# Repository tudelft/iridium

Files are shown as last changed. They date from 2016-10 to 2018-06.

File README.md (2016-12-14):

IRIDIUM IR9523 CARRIER BOARD
============================



Open-source carrier board for iridium IR9523 OEM modem.

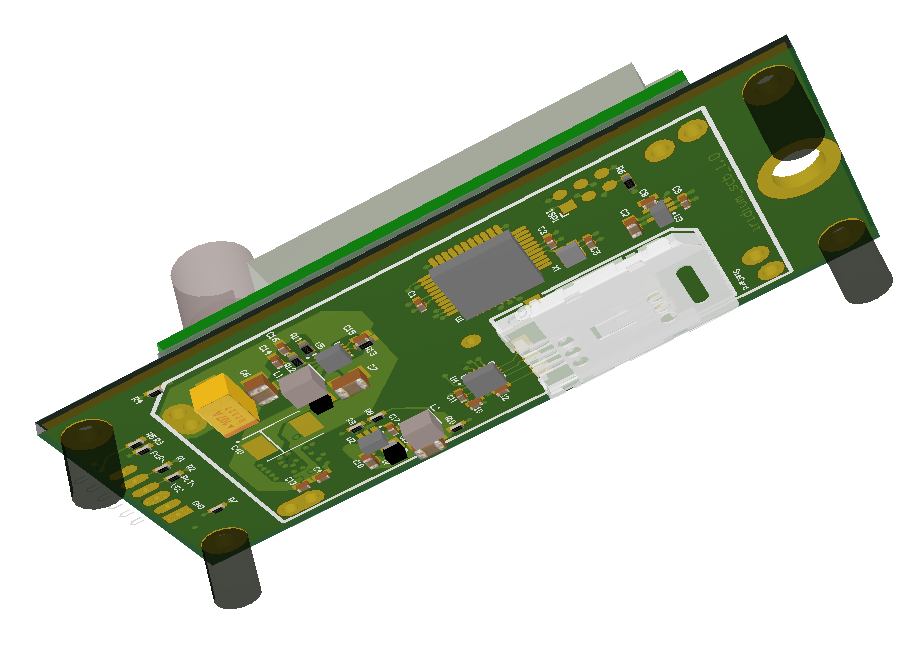
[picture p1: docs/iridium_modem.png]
Render of Iridium Carrier Board


Disclaimer:
-----------

 - An IRIDIUM IR9523 OEM module and an active subscription and simcard are required for this project.
 - The modems behave as transparent link. This means calls are answered automatically and all data sent to the module are tranmitted via space as soon as a connection is made.
 - Iridium antennas send strong signals and people must stay at a safe distance from the antenna. Consult all iridium documentation before use.

Licence:
--------

 - Software is released under **GPL3**
 - Hardware is released under **CC-BY-SA**

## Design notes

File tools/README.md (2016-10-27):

# Iridium Link
The Iridium Link tool configures the ground modem and initiates a call to the air modem. The ground modem firmware acts as an forwarder to the IR9523 OEM modem. This way the ground can be configured to call every number and forward all data over UDP.

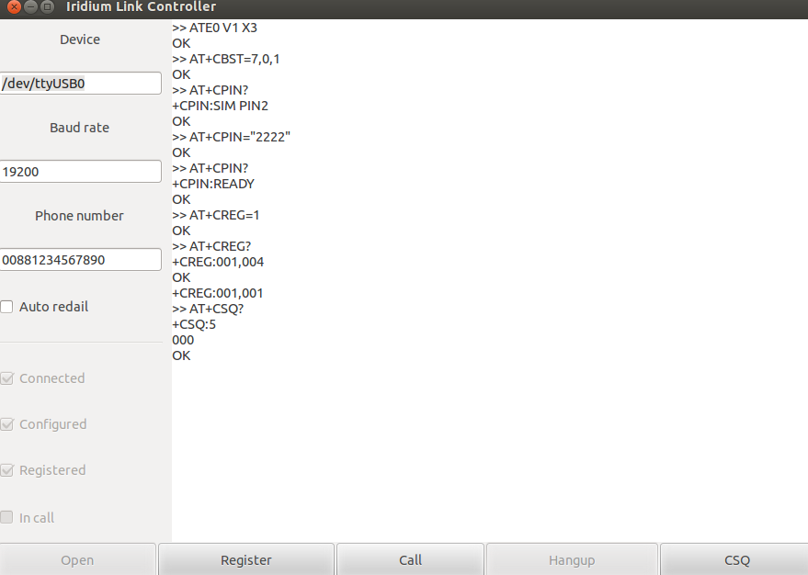
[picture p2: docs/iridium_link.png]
Iridium Link Program


## How to make a call
- Connect your ground modem with a serial cable to your computer (make sure it has the correct firmware)
- Start the `iridium_link.py` and enter the correct Serial port
- Press 'Open', this will setup the modem with the correct settings
- Press 'Register' to register the iridium device in the network
- Enter the correct phone number in the dialog
- Press 'Call' to initiate a call (this can take some time)

## Prerequisites
- pygtk 2.24.2
- pyserial 3.1.1
- Twisted 16.4.1

## FAQ

### I get a 'NO CARRIER' back
Please make sure you see the 'Registered' box checked, if not make sure you pressed 'Register'. Make sure the phone number is also correct. If both are correct try to press 'CSQ' which will return a signal quality, if this is '0' make sure you have placed your antenna aming at a clear sky.

### Where do I get the data
This tool will output data by default on UDP port '4242' and data can be send to UDP port '4243' on the local host. This will work by default with the Paparazzi Autopilot UDP link.

### I changed the SIM pin number
Make sure you also update the PIN number into the tool (this will be changeable in later versions). If not it won't be able to register.

### I cannot register to the network
If the 'Registered' box is never checked make sure your SIM card is correctly placed in the ground modem. Also make sure that your SIM card is activated by your provider.

### The ground modem doesn't respond
Make sure the ground modem is connected and turned on. Also make sure that the ground modem has the correct firmware (The ground and air modem have different versions).

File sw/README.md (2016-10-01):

# Firmware
 - the air modem is best programmed with iridium_air.hex which has firmware to automatically answer calls.
 - when also using iridium as ground modem, the board is best flashed with transparent firmware iridium_ground.hex. Use the python tool from the [tools](../tools) folder to dial.

## How to build
To build the software you have to run `make` in the `sw` folder. This will produce both the `iridium_air.elf` and the `iridium_ground.elf`.

## How to flash
To flash you either need to enter `make ground_program` or `make air_program` respectively for the ground and the air module. Note that this is using `avrdude` with an `avrispmkII` programmer.
If needed you can set the programmer using the `AVR_PROG=avrispmkII` make define.

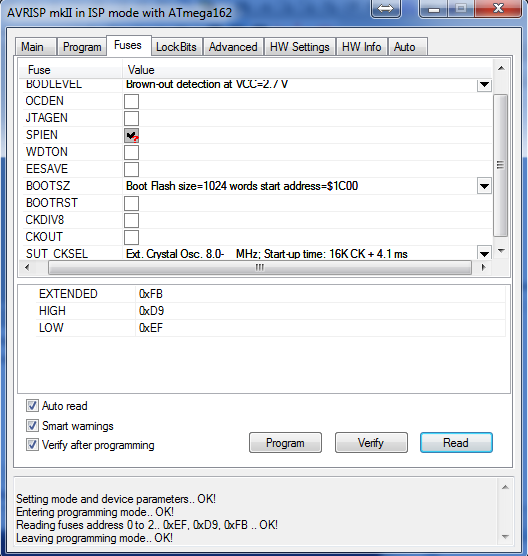
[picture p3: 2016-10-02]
sw/fuses.png

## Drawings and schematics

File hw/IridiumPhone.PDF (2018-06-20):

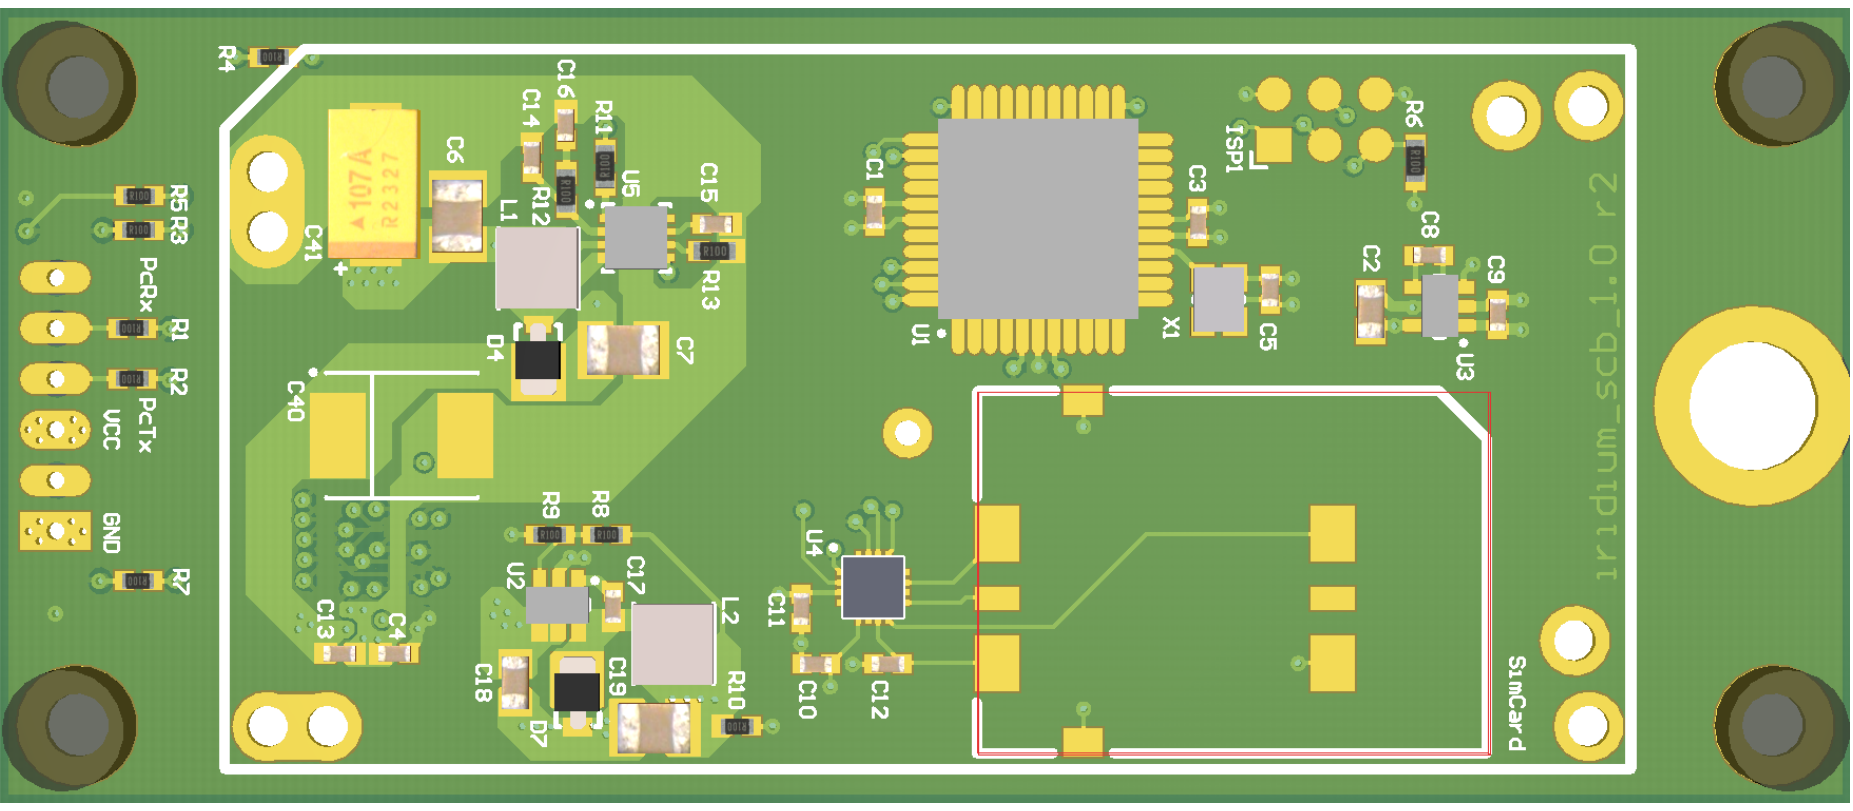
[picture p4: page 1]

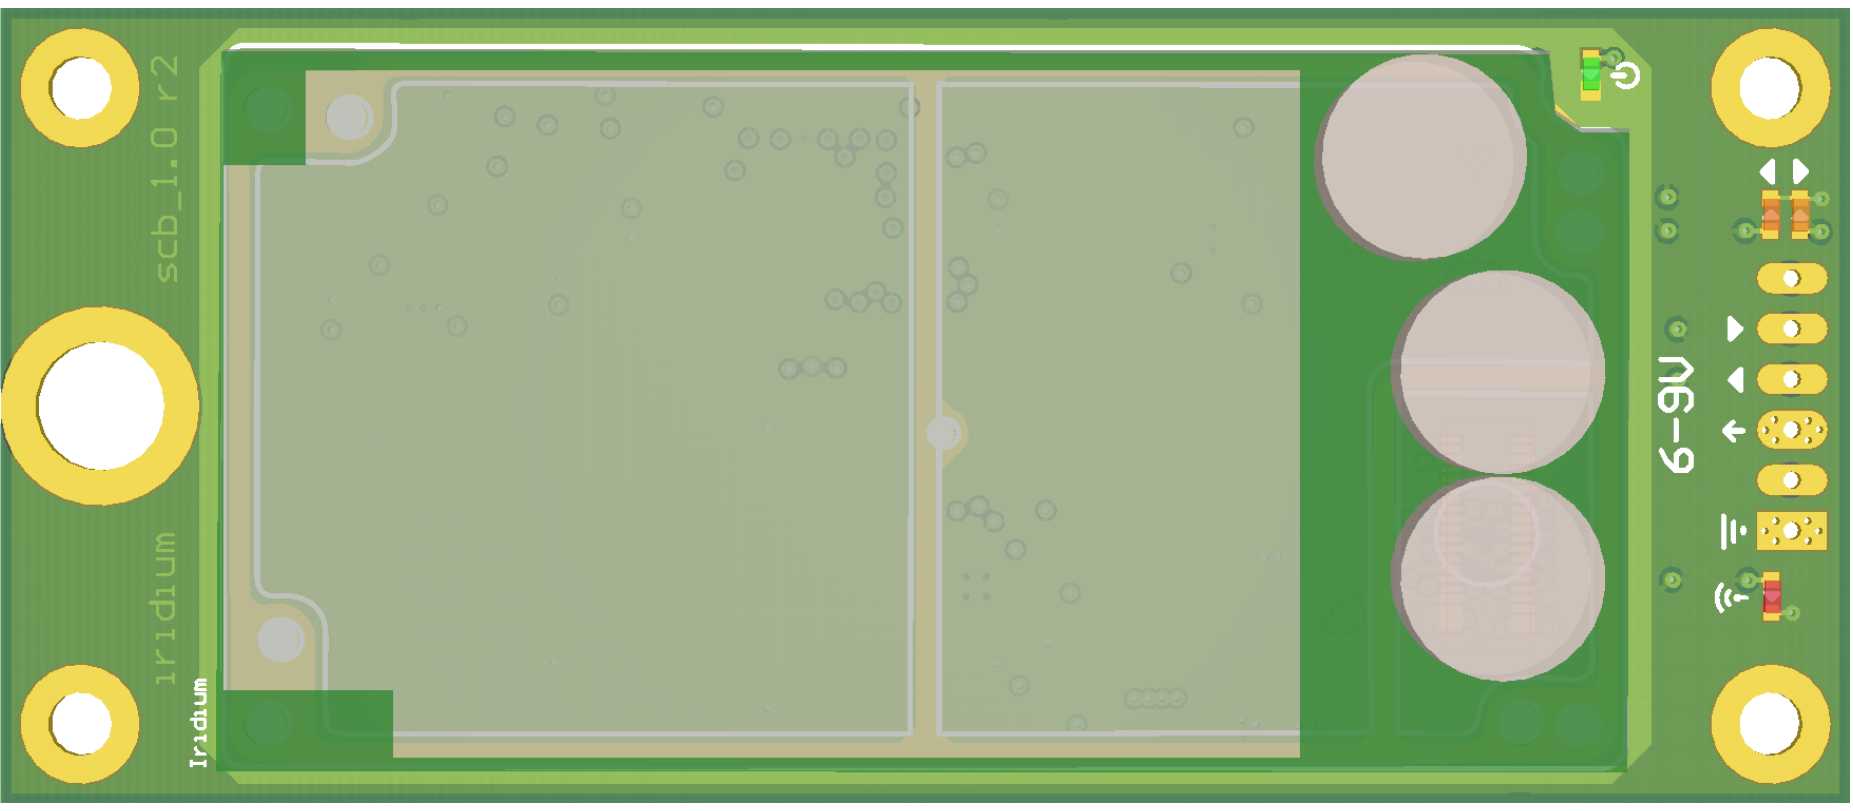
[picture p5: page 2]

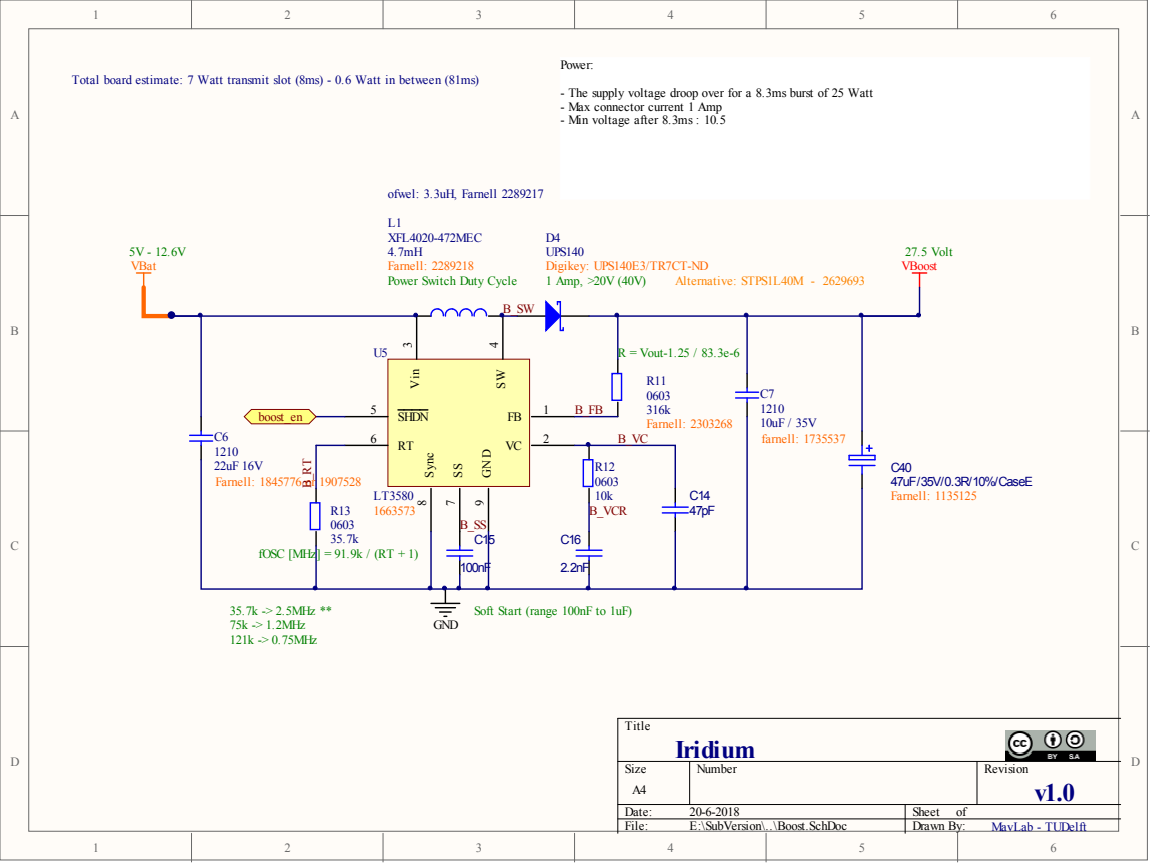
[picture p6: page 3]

Total board estimate: 7 Watt transmit slot (8ms) - 0.6 Watt in between (81ms)

- The supply voltage droop over for a 8.3ms burst of 25 Watt
- Max connector current 1 Amp
- Min voltage after 8.3ms : 10.5

Soft Start (range 100nF to 1uF)

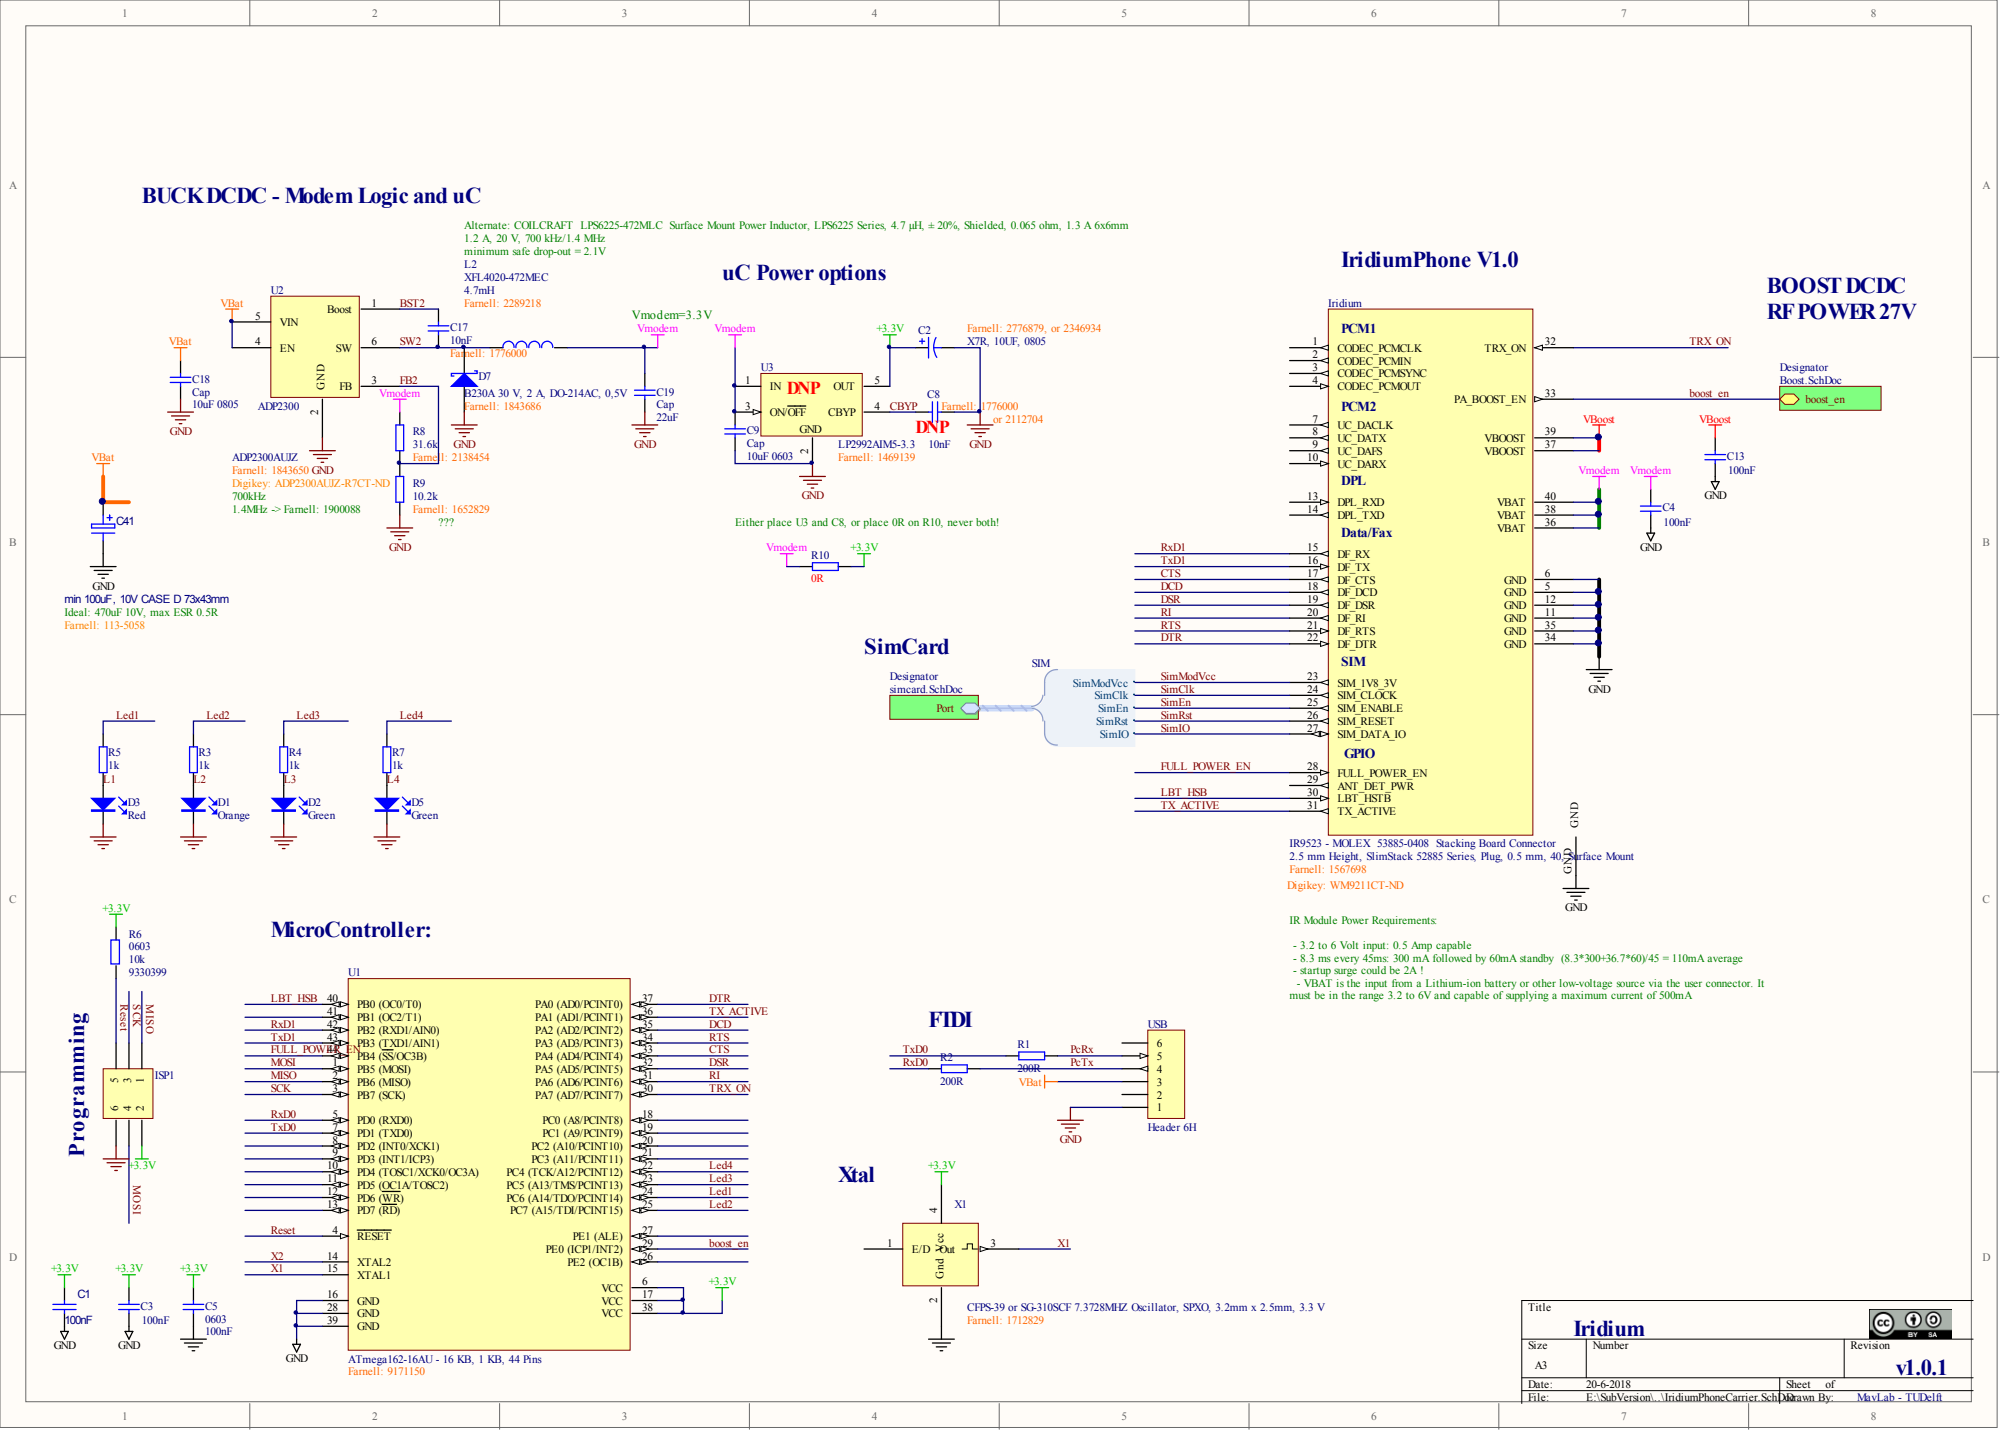
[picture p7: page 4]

BUCKDCDC - Modem Logic and uC

Alternate: COILCRAFT LPS6225-472MLC Surface Mount Power Inductor, LPS6225 Series, 4.7 µH, ± 20%, Shielded, 0.065 ohm, 1.3 A 6x6mm
1.2 A, 20 V, 700 kHz/1.4 MHz
minimum safe drop-out = 2.1V
XFL4020-472MEC
Farnell: 2289218

Either place U3 and C8, or place 0R on R10, never both!

IR9523 - MOLEX 53885-0408 Stacking Board Connector
2.5 mm Height, SlimStack 52885 Series, Plug, 0.5 mm, 40, Surface Mount
Farnell: 1567698
Digikey: WM9211CT-ND

IR Module Power Requirements:

- 3.2 to 6 Volt input: 0.5 Amp capable
- 8.3 ms every 45ms: 300 mA followed by 60mA standby (8.3*300+36.7*60)/45 = 110mA average
- startup surge could be 2A !
- VBAT is the input from a Lithium-ion battery or other low-voltage source via the user connector. It
must be in the range 3.2 to 6V and capable of supplying a maximum current of 500mA

CFPS-39 or SG-310SCF 7.3728MHZ Oscillator, SPXO, 3.2mm x 2.5mm, 3.3 V
Farnell: 1712829

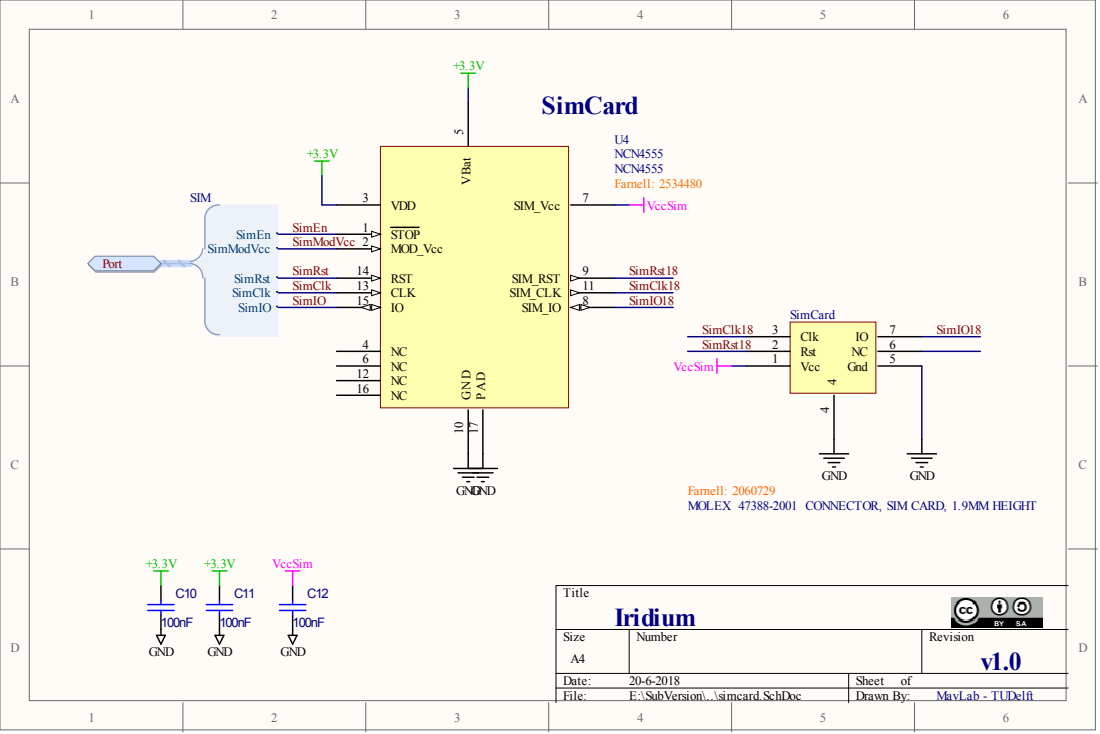
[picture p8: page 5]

Farnell: 2060729
MOLEX 47388-2001 CONNECTOR, SIM CARD, 1.9MM HEIGHT

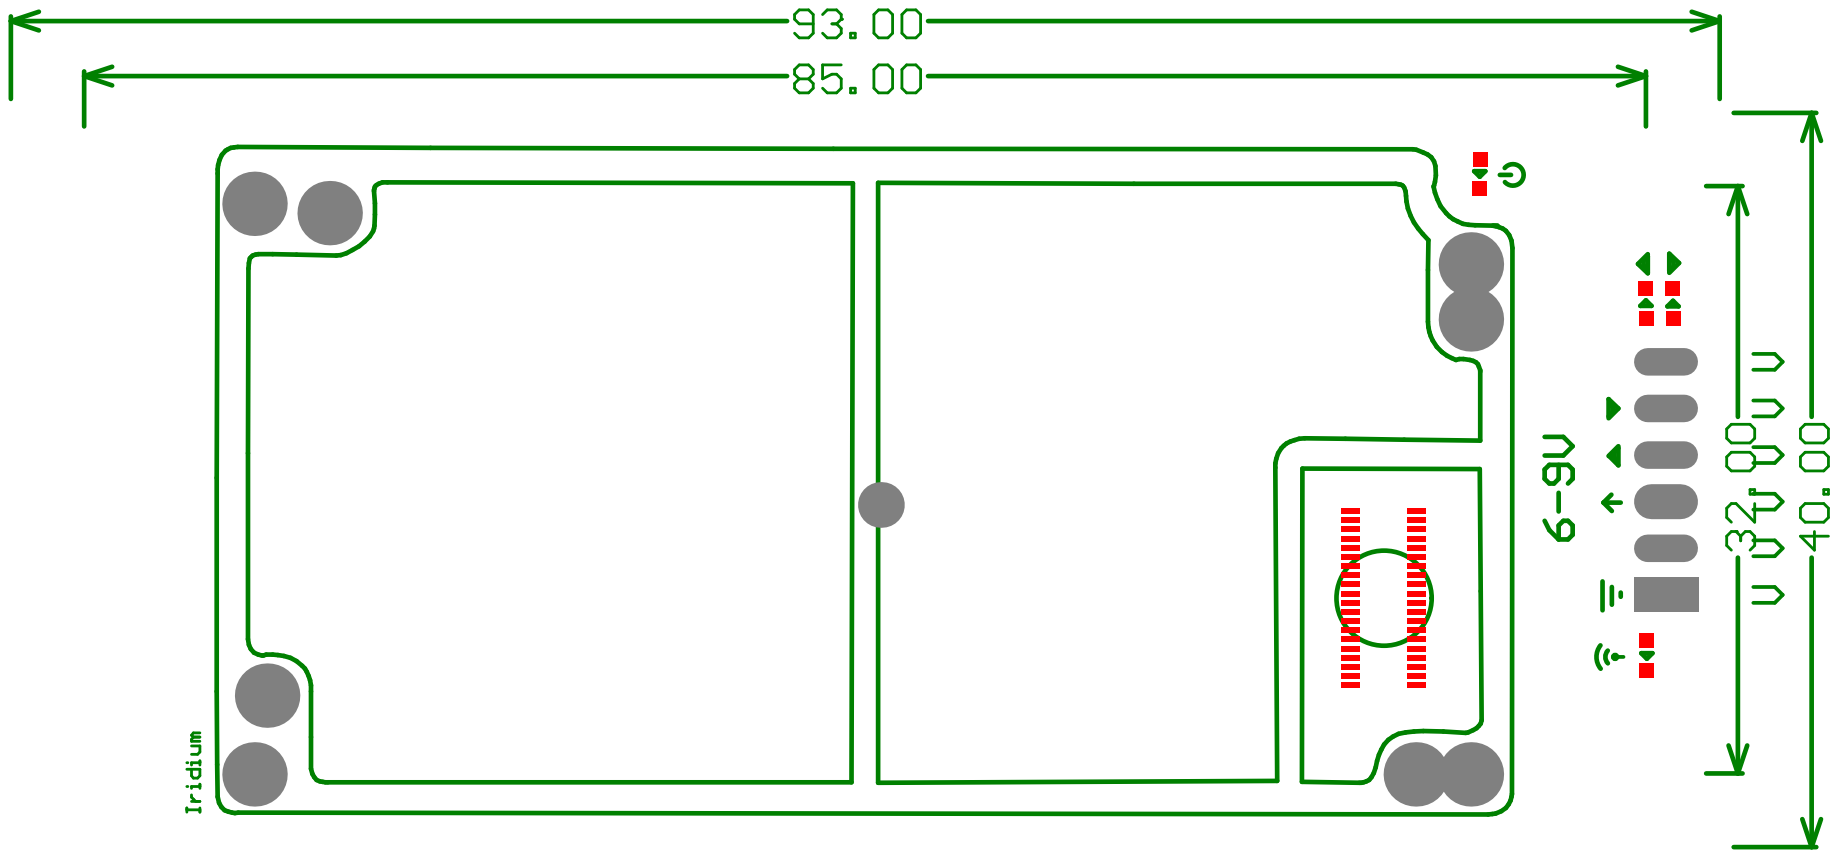
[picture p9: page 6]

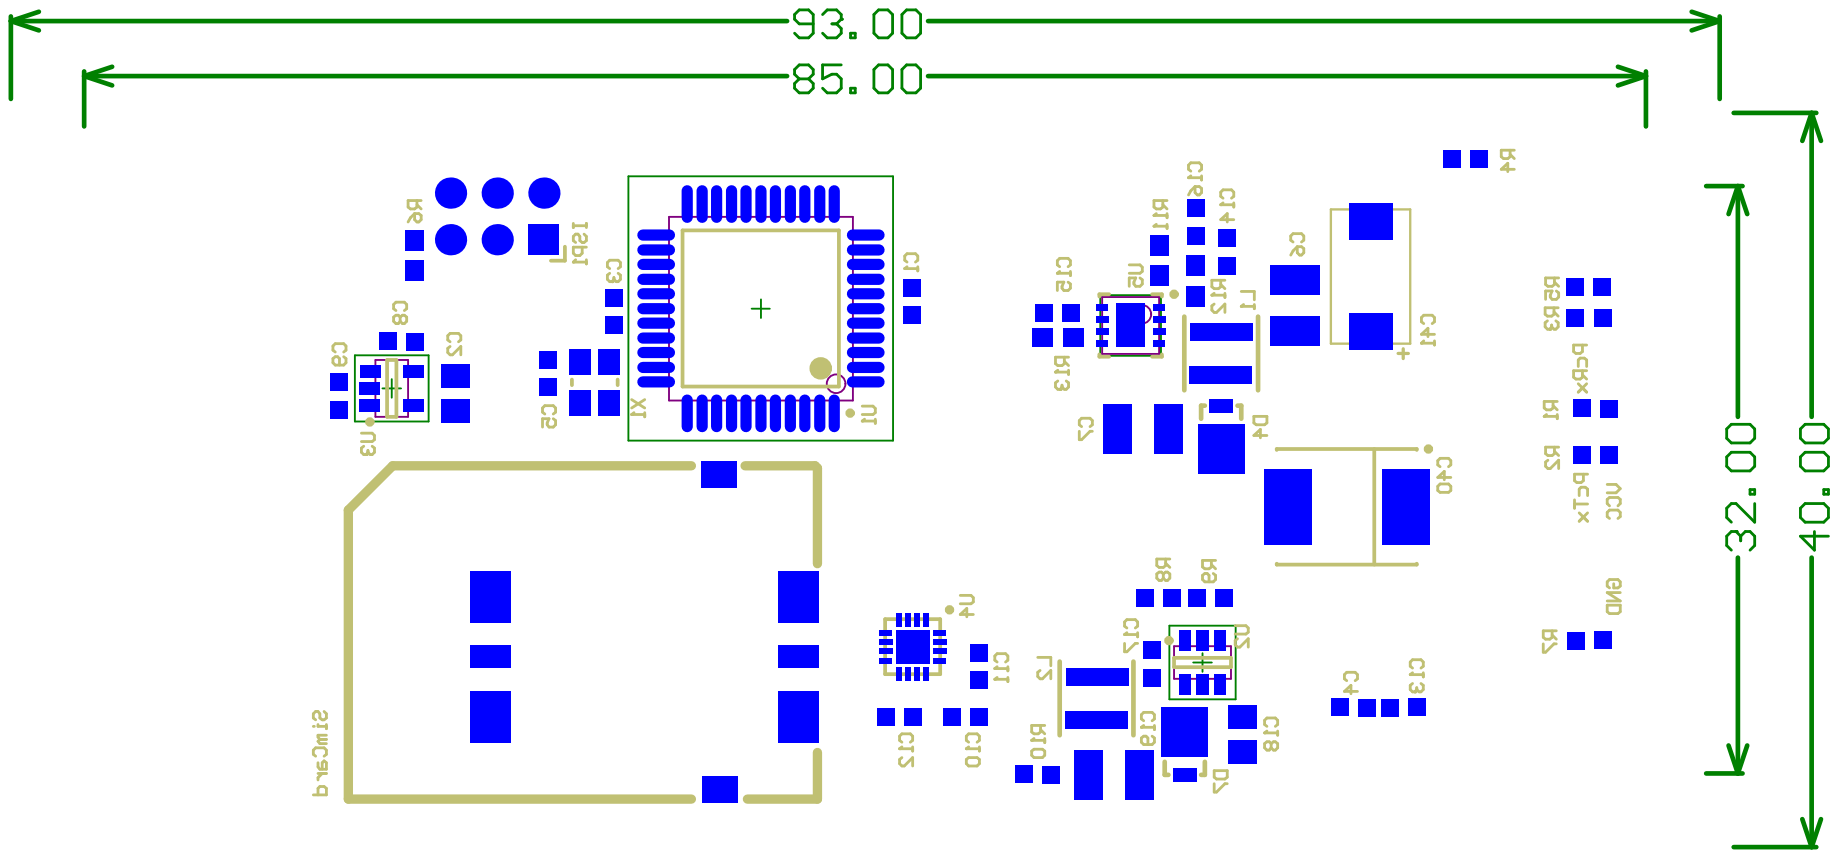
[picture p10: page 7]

Quantity | Designator | value | Footprint | Comment | Description | Farnell | LibRef
1 | C40 | | E | 47uF/ 35V/ 0.3R/10 %/ CaseE | | 1135125 | ELECTRO1
1 | C41 | | T491D | min 100uF, 10V CASE D 73x43mm | | 113-5058 | ELECTRO1
1 | Iridium | | iridiumphone | IR9523 - MOLEX 53885-0408 Stacking Board Connector | | 1567698 | IR9523
1 | SimCard | | simcard | MOLEX 47388-2001 CONNECTOR, SIM CARD, 1.9MM HEIGHT | | 2060729 | SIMCARD
1 | U1 | | 44A_M | ATmega162-16AU -16 KB, 1 KB, 44 Pins | 8-Bit AVR Microcontroller with 16K Bytes of In-System Programmable Flash Memory | 9171150 | ATmega162-16AC
1 | U5 | | DFN-MF8 | LT3580 | Boost DCDC | 1663573 | LT3580
2 | D4, D7 | | DO-216AA | B230A 30 V, 2 A, DO-214AC, 0,5V, UPS140 | Silicon RF Schottky Diode for Mixer Applications in the VHF/ UHF Range | 1843686 | Diode BAT17
4 | D1, D2, D3, D5 | | KP-1608SURC_R | D11 | Diode, LED | | D11
1 | R10 | 0R | V0603RES | | Resistor | | R12
4 | R3, R4, R5, R7 | 1k | V0603RES | R12 | Resistor | | R12
2 | L1, L2 | 4.7mH | XFL4020 | XFL4020-472MEC | Inductor | 2289218 | Inductor
2 | R6, R12 | 10k | 0603RES | 0603 | RESISTOR, 0603 10K | 9330399 | Res2
2 | C8, C17 | 10nF | V0603 | Cap | Capacitor | 1776000 | Cap
1 | C9 | 10uF 0603 | V0603 | Cap | Capacitor | | Cap
1 | C18 | 10uF 0805 | V0805 | Cap | Capacitor | | Cap
1 | C7 | 10uF / 35V | 1210 | 1210 | Ceramic Chip Capacitor -Standard | 1735537 | C0603
1 | R9 | 10.2k | V0603RES | R12 | Resistor | 1652829 | R12
1 | X1 | 16MHz | CRY_2_5x3_2 | Xtal Osc | Crystal Oscilator | 1712829 | CFPS-39 2.5 x 3mm 16MHz
1 | C19 | 22uF | 1210 | Cap | Capacitor | | Cap
1 | C6 | 22uF 16V | 1210 | 1210 | Ceramic Chip Capacitor -Standard | 1845776 or 1907528 | C0603
1 | R8 | 31.6k | V0603RES | R12 | Resistor | 2138454 | R12
1 | R13 | 35.7k | 0603RES | 0603 | RESISTOR, 0603 10K | | Res2
11 | C1, C3, C4, C5, C10, C11, C12, C13, C14, C15, C16 | 100nF | V0603 | 2.2nF, 47pF, 100nF, 0603 | Ceramic Chip Capacitor -Standard | | C0603, CAP
2 | R1, R2 | 200R | V0603RES | R12 | Resistor | | R12
1 | R11 | 316k | 0603RES | 0603 | RESISTOR, 0603 10K | 2303268 | Res2
1 | U2 | ADP2300AUJZ | SOT-23-OT6_N | ADP2300 | SOT23-6 DCDC Switcher | 1843650 | LM2734
1 | U3 | LP2992AIM5-3.3 | MF05A_N | LP2992AIM5-3.3 | Micropower 250 mA Low-Noise Ultra Low-Dropout Regulator, 5-pin SOT-23 | 1469139 | LP2992AIM5-3.3
1 | U4 | NCN4555 | QFN16_3MM | NCN4555 | | 2534480 | NCN4555
1 | C2 | X7R, 10UF, 0805 | V0805 | TAJR475K006RNJ | Polarized Capacitor (S277687 9, or 2346934Cap Pol3

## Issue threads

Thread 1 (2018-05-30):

Incomplete Gebers

DavidIngraham, 2018-05-30:
First off, thanks for making this awesome piece of hardware open! It opens the doors to some very cool operations.

It seems that the released Gerber files are incomplete. There is no GBO (bottom silkscreen) or paste layers. Would it be possible to provide these?

Thanks,

David Ingraham

dewagter, 2018-05-30:
Thank you for your interest. The issue should be solved with 9808fa04a11ecb473359963aeba16ecd684d837c

dewagter, 2018-06-04:
Attention: accidentally, Revision 1 gerbers were added instead of revision 2. d7844c18a788b5a06bf1a5526d2c530d19a2a9a9 solves this issue.

DavidIngraham, 2018-06-04:
Great, thank you for that.

One thing that would also be helpful is if you could upload the OBD++ files. These files also contain component placement information that allow for automated manufacturing.

Macrofab has a great guide here on how to export these files from Altium: https://macrofab.com/help/eda-tool-help/altium/

dewagter, 2018-06-05:
Pick & Place file added, ODB+ and Altium Source

fvantienen, 2018-06-05:
Are you going to make multiple boards? Is there any chance you could make 1 extra?

DavidIngraham, 2018-06-08:
Sure, I can manage a group order if you all are interested. We can work out the details over PM.

DavidIngraham, 2018-06-11:
I'm getting ready to place the order today. There are a few components where the PN on the schematic is different from the PN in the mechanical files. I noticed that the Schematic PDF is R1, is there an updated R2 schematic that I can reference to ensure I am ordering the correct PNs for this version?

fvantienen, 2018-06-11:
R2 is only a PCB trace change. Which component is a problem?

DavidIngraham, 2018-06-12:
The two main issues I see:

1. C41 is specified to be a 470uF/6V part but it receivees the full input voltage (Up to 8.4V) What part did you actually use?
2. X1 is specified as Farnell Part number 1712829 (Epson Q33310F700245 SG-310SCF) There are conflicting notes that specify a 16MHz Crystal. Just wanted to confirm if this is the correct part number.

DavidIngraham, 2018-06-12:
ALso, I wanted to confirm that the correct part number for the uC is ATMEGA162-16AU

dewagter, 2018-06-20:
See https://github.com/tudelft/iridium/issues/3

Closed 2018-05-30.

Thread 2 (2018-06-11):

Add DCDC computations

dewagter, 2018-06-11:
Note: the current power converters are designed with an input voltage of 6 to  8.4 Volt in mind. (2 cell lithium). Re-compute the power supplies if other inputs are used.

Closed 2018-06-11.

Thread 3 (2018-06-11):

Assembly Details

dewagter, 2018-06-11:
I assembled my boards with U3 and C8 left unpopulated and R10 fitted with a zero ohm as the ADP2300 is now set up to give 3.3V.

dewagter, 2018-06-20:
- uC is ATMEGA162-16AU
 - C41 we used a 330uF 10V, but 470uF 10V would be better if you can source it
 - X1 should not be a crystal but an oscillator circuit of 7.3728MHZ, which allows for perfect baud rates and is less than the max 8MHz that the Atmel can run at 3.3V

Closed 2018-06-21.

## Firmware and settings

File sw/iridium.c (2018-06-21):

/*
    This file is part of IridiumCarrierBoard.

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
    You should have received a copy of the GNU General Public License
    along with IridiumCarrierBoard.  If not, see <http://www.gnu.org/licenses/>.
*/


/**
 *	\file iridium.c Main Loop
 *
 *	
 *	- Fuses:
 *		- Brown Out Detector @ 1.8Volt: reset on bad voltage
 *		- Watchdog Timer disabled
 *		- OnChip Debug disables
 *		- JTAG Disabled
 *		- Reset Normal (do not check disable)
 *		- Bootloader : 1024 Words
 * 
 */


#include "usart.h"

/**
 *	\brief	Periodic Run
 *
 */
 
#include <avr/io.h>
#include <util/delay.h>
#include <avr/interrupt.h>

#include "ir9523.h"

volatile uint8_t led_rx = 0;
volatile uint8_t led_tx = 0;
volatile uint8_t dcd = 0;

ISR(TIMER1_OVF_vect)
{
	if (dcd > 0)
	{
		PORTC |= _BV(GREEN);
	}
	else
	{
		static uint8_t green = 0;
		green++;
		if (green > 15)
		{
			PORTC ^= _BV(GREEN);
			green = 0;
		}
	}
	
	if (led_rx > 0)
	{
		led_rx--;
	}
	else
	{
		PORTC &= ~ _BV(ORANGE2);
	}
	if (led_tx > 0)
	{
		led_tx--;
	}
	else
	{
		PORTC &= ~ _BV(ORANGE1);
	}
}

#define BLINK_LENGTH 7

static inline void RX_LED(void)
{
	led_rx = BLINK_LENGTH;
	PORTC |= _BV(ORANGE2);
}


static inline void TX_LED(void)
{
	led_tx = BLINK_LENGTH;
	PORTC |= _BV(ORANGE1);
}


void sys_time_init(void)
{
	// 7372800Hz -> 1024 * 72 * 100Hz
	// Mode 14, clock/1024, count to ICR
	TCCR1A = (2 << WGM10);
	ICR1 = 72;
	TCCR1B = (3 << WGM12) | (5 << CS10);
	TIMSK = (1 << TOIE1);
}



int main(void)
{
	////////////////////////
	// LED
	DDRC |= _BV(GREEN) | _BV(RED) | _BV(ORANGE1) | _BV(ORANGE2);
	PORTC |= _BV(GREEN) | _BV(RED) | _BV(ORANGE1) | _BV(ORANGE2);



	////////////////////////
	// POWER:
	// BOOST: input
	DDRE &= ~ _BV(BOOST_ENABLE);
	PORTE |= _BV(BOOST_ENABLE);		// Pull-up just in case: to make 27 Volt
	

	
	////////////////////////
	// MODEM STATUS
	DDRA &= ~( _BV(TXACT) | _BV(DCD) | _BV(CTS)  | _BV(DSR) | _BV(RI) );
	// Pull-Up Inputs
	// PORTA &= ~( _BV(TXACT) | _BV(DCD) | _BV(CTS)  | _BV(DSR) | _BV(RI) );

	
	////////////////////////
	// MODEM CONTROLS
	DDRA |= _BV(DTR) | _BV(RTS) | _BV(TRXON);
	DDRB |= _BV(LBT_HSB) | _BV(FULLPOWER);

	// Communication Enable
	PORTA &= ~(_BV(RTS) | _BV(DTR));
	
	// LBT_HSB: anntenna is pulled out -> 3.3V: Allow full power transmit
	PORTB |= _BV(LBT_HSB);
	
	// Full power enable
	PORTB |= _BV(FULLPOWER);
	
	// TRX_ON: Turn modem om
	PORTA |= _BV(TRXON);
	
	
	

	////////////////////////
	// Drivers
	
	// SERIAL
	Usart_Init();
	
	// TIMER
	sys_time_init();
	
	// Initialize (before interrupts are enabled)
#ifdef MODEM_TYPE_AIR
#warning AIR_MODEM AUTO CONFIG
	iridium_setup();
#endif
	
	// Start Interrupts
	sei();

	// Main loop
    for (;;)
    {
		char c;

		// DCD: Data Donnection Detected
		if ((PINA & _BV(DCD)) != 0)
		{
			dcd = 0;
		}
		else
		{
			dcd = 1;
		}
		
		
		// Read data and forward
		if (Uart0_Has_Data())
		{
			c = Uart0_Rx();
			
#ifdef MODEM_TYPE_AIR
			// Only forward data from autopilot to the modem when Data Carrier Detect is active
			if (dcd > 0)
#endif
			{
				Uart1_Tx(c);
			}
			TX_LED();
 		}
		
		if (Uart1_Has_Data())
		{
			c = Uart1_Rx();
			Uart0_Tx(c);
			RX_LED();
		}
		
		
		// Transmit Active
		if ((PINA & _BV(TXACT)) != 0)
		{
			PORTC |= _BV(RED);
		}
		else
		{
			PORTC &= ~ _BV(RED);
		}
		
		
	}
	
	return 0; 
}

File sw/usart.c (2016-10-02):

/*
    This file is part of IridiumCarrierBoard.

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
    You should have received a copy of the GNU General Public License
    along with IridiumCarrierBoard.  If not, see <http://www.gnu.org/licenses/>.
*/


/**
 *	\file usart.c
 */


#include "usart.h"
#include <avr/interrupt.h>


/**
 *
 *	RECEIVE INTERRUPTS
 *
 */

// Interrupt routine variable (multithreaded)
volatile uint8_t uart0_write = 0;
volatile uint8_t uart0_read = 0;
volatile uint8_t uart0_ready = TRUE;
volatile uint8_t uart0_isr_buffer[USART0_BUFFER_SIZE];

ISR(USART0_RXC_vect)
{
	uint8_t pnt=uart0_write;

	// Fill circular buffer
	uart0_isr_buffer[uart0_write] = UDR0;
	pnt++;
	
	if (pnt == uart0_read)
	{
		//PORTC ^= _BV(PORTC3);
	}
	else
	{
		uart0_write++;
	}
}

ISR(USART0_UDRE_vect)
{
	UDR0 = uart0_isr_buffer[uart0_write];
	uart0_write++;
	
	if(uart0_isr_buffer[uart0_write] == 0)
	{
		UCSR0B &= ~ (1<<UDRIE0);
		uart0_ready = TRUE;
	}
}


/**
 *
 *	TRANSMIT INTERRUPTS
 *
 */

volatile uint8_t uart1_write = 0;
volatile uint8_t uart1_read = 0;
volatile uint8_t uart1_ready = TRUE;
volatile uint8_t uart1_isr_buffer[USART1_BUFFER_SIZE];

ISR(USART1_RXC_vect)
{
	uint8_t pnt=uart1_write;

	// Fill circular buffer
	uart1_isr_buffer[uart1_write] = UDR1;
	pnt++;
	
	if (pnt == uart1_read)
	{
		//PORTC ^= _BV(PORTC3);
	}
	else
	{
		uart1_write++;
	}
}

ISR(USART1_UDRE_vect)
{
	UDR1 = uart1_isr_buffer[uart1_write];
	uart1_write++;
	
	if(uart1_isr_buffer[uart1_write] == 0)
	{
		UCSR1B &= ~ (1<<UDRIE1);
		uart1_ready = TRUE;
	}
}

void Usart1_Tx(void)
{
	cli();
	if (uart1_ready != TRUE)
		return;
	
	uart1_ready = FALSE;
	uart1_write = 0;
	UCSR1B |= (1<<UDRIE1);
	sei();
}



// UART0
void Uart0_Tx(char data)
{
    while (!(UCSR0A & (1<<UDRE0)));
    UDR0 = data;
}

void Uart0_Tx_String(char* data)
{
	int i = 0;
	while (data[i] != '\0')
	{
		Uart0_Tx(data[i]);
		i++;
	}
}


char Uart0_Rx(void)
{
    while (!(UCSR0A & (1<<RXC0)))
		;
    return UDR0;
}

char Uart0_Has_Data( void )
{
	return ((UCSR0A & (1<<RXC0)));
}

// UART1
void Uart1_Tx(char data)
{
    while (!(UCSR1A & (1<<UDRE1)));
    UDR1 = data;
}

void Uart1_Tx_String(char* data)
{
	int i = 0;
	while (data[i] != '\0')
	{
		Uart1_Tx(data[i]);
		i++;
	}
}


char Uart1_Rx(void)
{
    while (!(UCSR1A & (1<<RXC1)))
		;
    return UDR1;
}

char Uart1_Has_Data( void )
{
	return ((UCSR1A & (1<<RXC1)));
}

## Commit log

2016-10-02 r1 schematics
2016-10-02 [firmware] fuses
2016-10-02 [tools] Add ground station tool
2016-10-02 GERBER/NC files
2016-10-02 [firmware] precompiled hex for air (auto-answer) and transparent ground (external dialup tool)
2018-05-30 Gerbers for solder paste masks top and bottom and gerber for bottom overlay
2018-06-04 Bugfix: IrPhR2.zip contained R1 gerbers
2018-06-05 Add Altium Designer source file
    [IridiumPhone_r2.PcbDoc]
2018-06-11 DCDC computations: closes #2
    [DCDC.xlsx]
2018-06-20 Update docs: C41 voltage to 10V, Processor ATMEGA162-16AU, Oscillator 7.37MHZ, DNP U3 and C8, R10=0R solves #3
2018-06-21 Update ground software

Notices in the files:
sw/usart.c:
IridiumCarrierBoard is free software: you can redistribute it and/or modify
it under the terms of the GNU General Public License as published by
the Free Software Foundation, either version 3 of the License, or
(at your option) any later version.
